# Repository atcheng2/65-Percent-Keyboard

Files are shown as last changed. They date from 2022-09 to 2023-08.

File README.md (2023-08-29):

# 65-Percent-Keyboard



QMK Based Keyboard based on the ATmega32A and the VUSB protocol. This build
implements an ANSI 65% layout for standard MX-style switches. The ATmega32A is
implemented over the more standard ATmega32u4 that has native USB support due to
budget constraints and part availability.

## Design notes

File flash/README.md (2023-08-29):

# Basic Flashing Sequence

## Flashing USBaspLoader

1. Connect ISP pins on board to ISP programmer
2. Use `make check` to ensure a proper connection
3. When proper connection is ensured, use `make fuse` to set fuses
4. After fuses are set, use `make flash` flash USBaspLoader

The relevant hex file is `main.hex`, which was compiled using a modified version
of
[USBaspLoader-Atmega32](https://github.com/khairulhasanmd/USBaspLoader-Atmega32)
that takes into account the settings found in
[`bootloaderconfig.h`](bootloaderconfig.h).

## Flashing QMK

1. Connect device to computer via USB port
2. Short bootloader jumper on device and press the reset switch
3. If done properly, the board should be recognized as a USB device
4. Flash QMK with `make upload`

The relevant hex file is `andyboard_default.hex`, which was compiled using a
modified version of [QMK](https:github.com/atcheng2/qmk_firmware).

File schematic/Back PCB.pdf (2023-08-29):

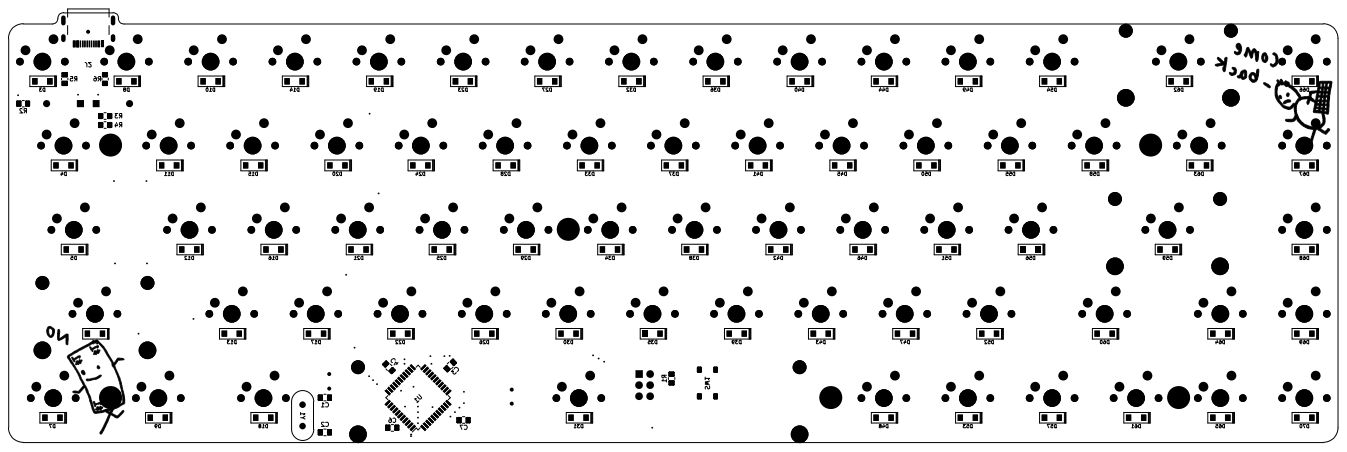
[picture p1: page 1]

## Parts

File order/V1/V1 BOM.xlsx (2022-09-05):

Comment | Designator | Footprint | JLCPCB Part #（optional）
ATMega32A-AU | U1 | TQFP-44_10x10mm_P0.8mm

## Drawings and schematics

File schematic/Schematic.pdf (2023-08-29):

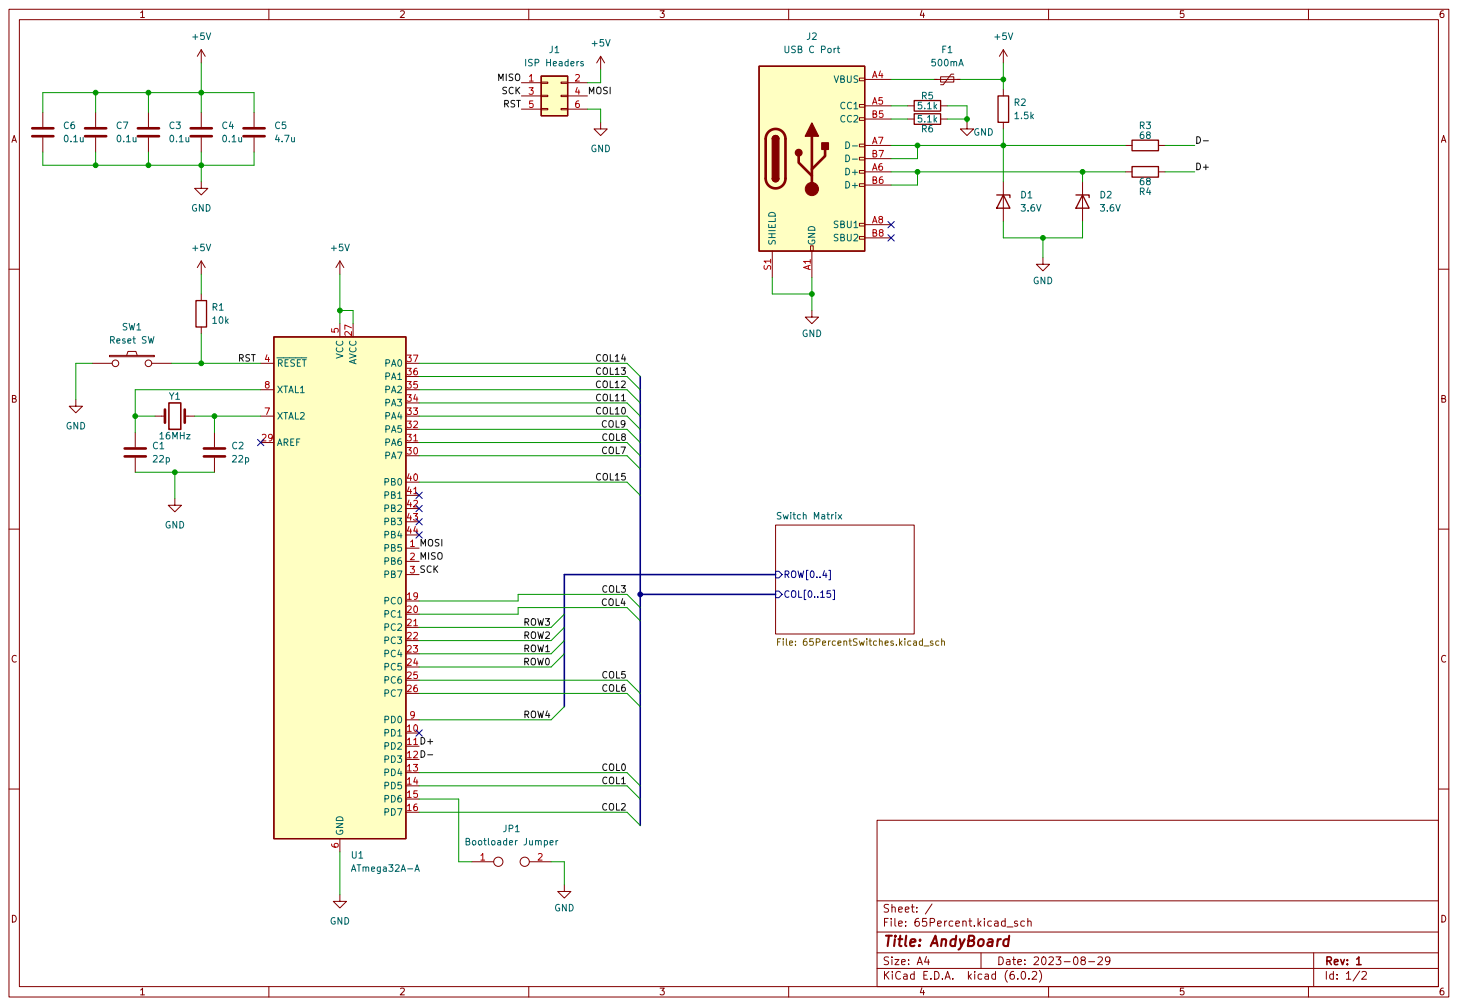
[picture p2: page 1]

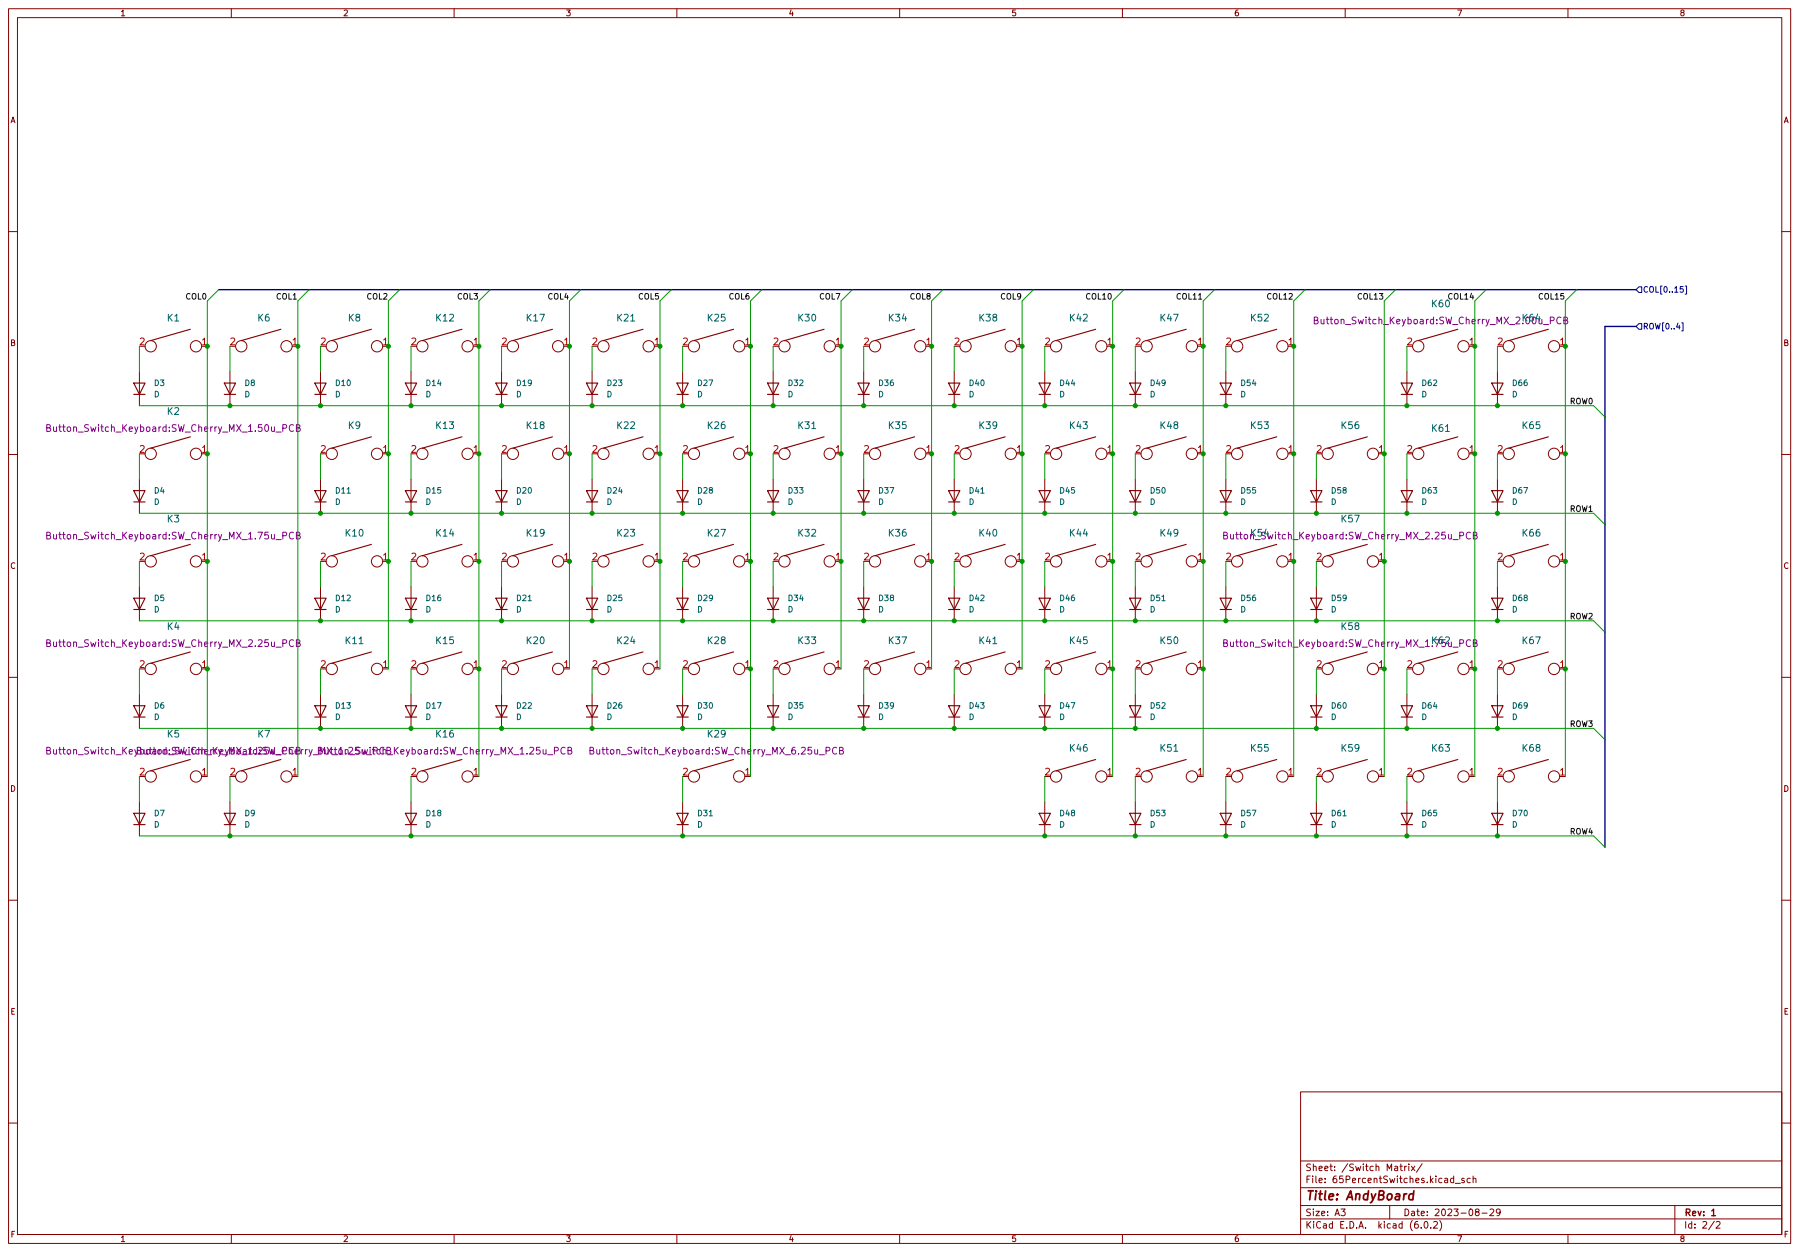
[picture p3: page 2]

File: 65PercentSwitches.kicad_sch Sheet: /Switch Matrix/
Id: 2/2 Title: AndyBoard

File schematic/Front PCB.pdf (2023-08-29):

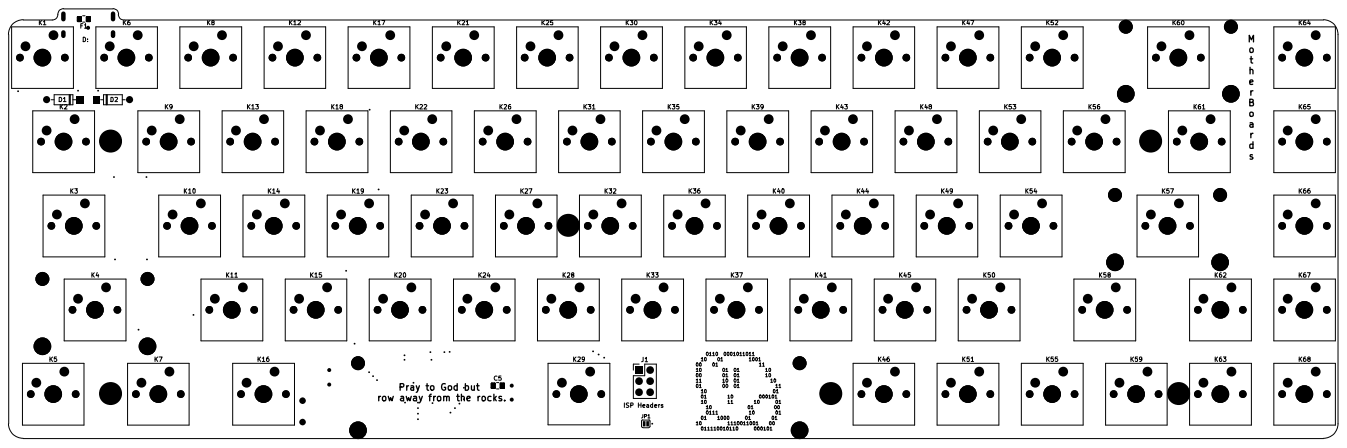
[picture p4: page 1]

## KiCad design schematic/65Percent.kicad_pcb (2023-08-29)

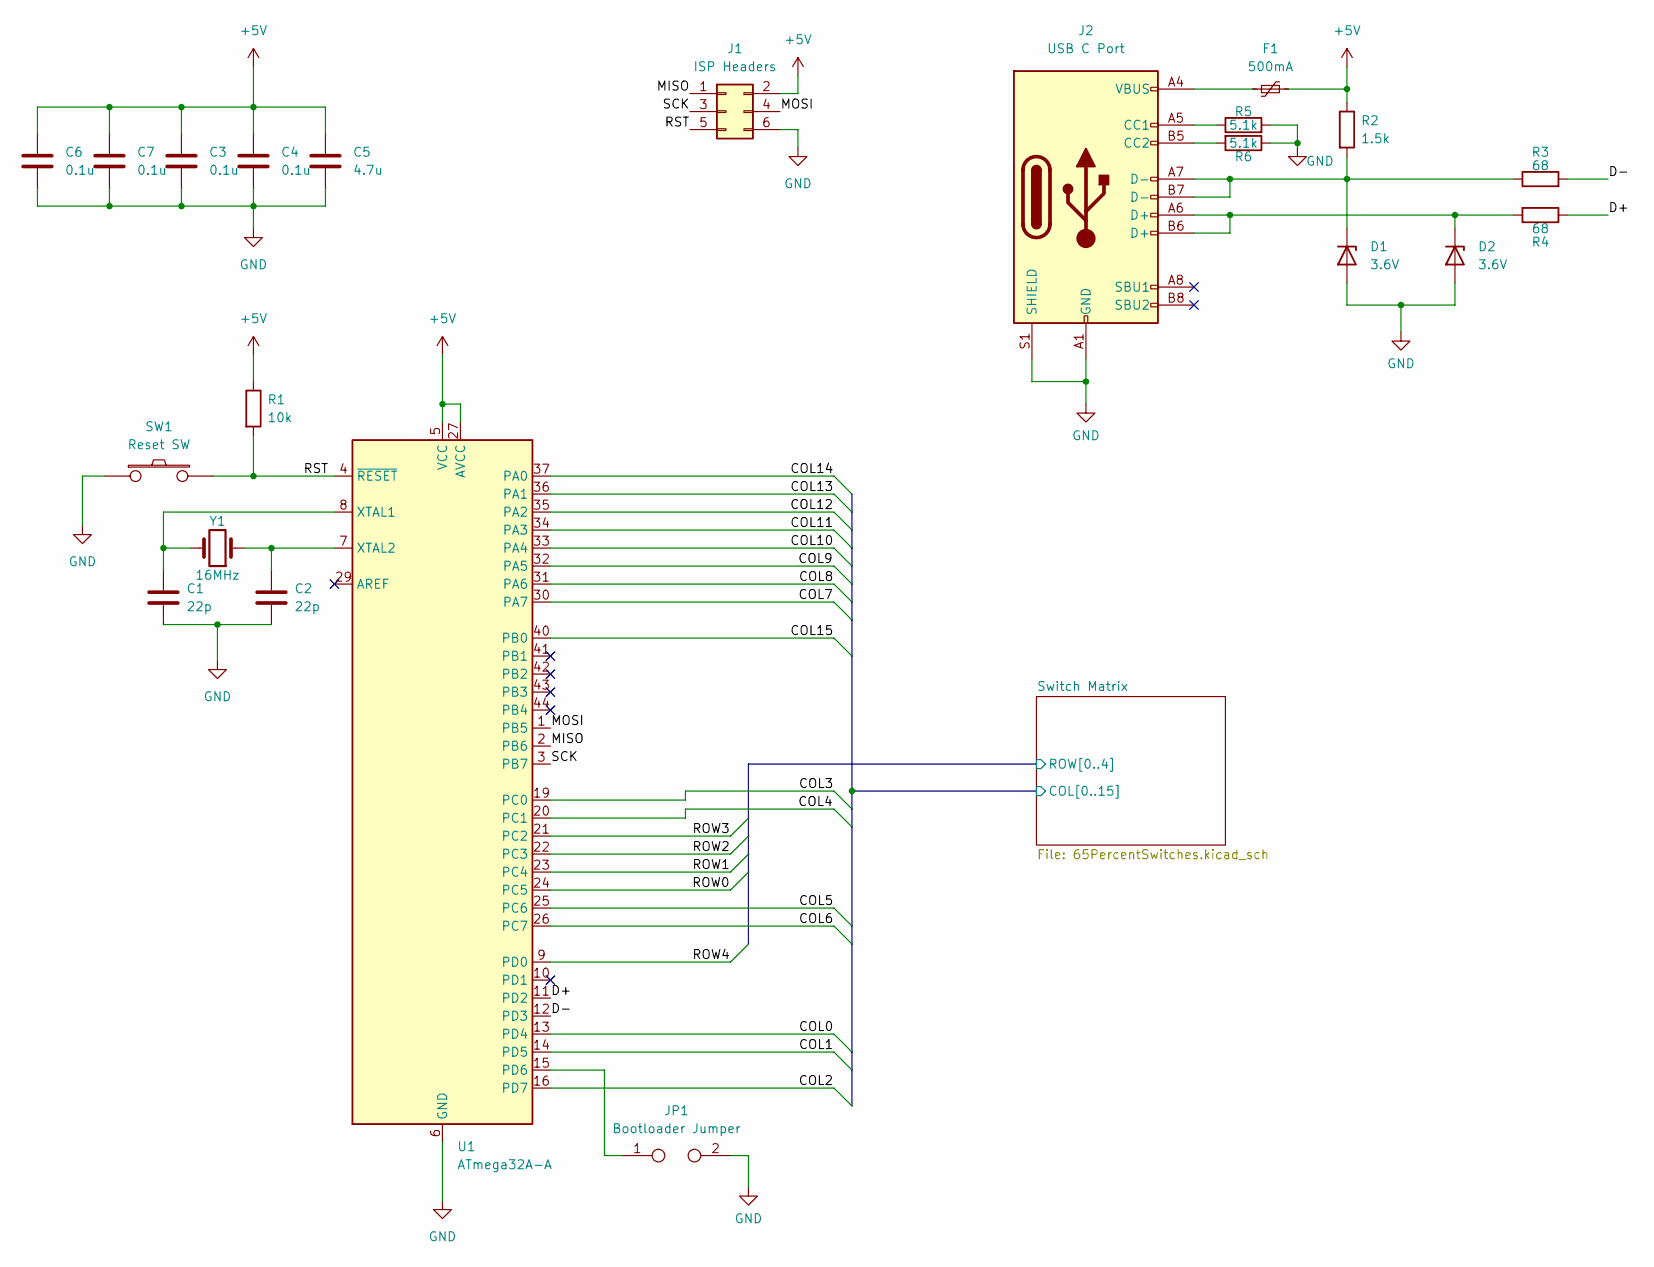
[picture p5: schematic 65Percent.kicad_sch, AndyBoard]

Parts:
C1, C2: 22p; C_0805_2012Metric_Pad1.18x1.45mm_HandSolder
C3, C4, C6, C7: 0.1u; C_0805_2012Metric_Pad1.18x1.45mm_HandSolder
C5: 4.7u; C_0805_2012Metric_Pad1.18x1.45mm_HandSolder
D1, D2: 3.6V; D_DO-35_SOD27_P7.62mm_Horizontal
F1: 500mA; Fuse_0805_2012Metric_Pad1.15x1.40mm_HandSolder
J1: ISP Headers; PinHeader_2x03_P2.54mm_Vertical
J2: USB C Port; USB_C_2169900002
JP1: Bootloader Jumper; SOLDER_JUMPER_2
R1: 10k; R_0805_2012Metric_Pad1.20x1.40mm_HandSolder
R2: 1.5k; R_0805_2012Metric_Pad1.20x1.40mm_HandSolder
R3, R4: 68; R_0805_2012Metric_Pad1.20x1.40mm_HandSolder
R5, R6: 5.1k; R_0805_2012Metric_Pad1.20x1.40mm_HandSolder
SW1: Reset SW; Pushbutton_PTS526
U1: ATmega32A-A; TQFP-44_10x10mm_P0.8mm
Y1: 16MHz; Clock_THT

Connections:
+5V: C3.1, C4.1, C5.1, C6.1, C7.1, F1.2, J1.2, R1.1, R2.1, U1.5 (VCC), U1.17 (VCC), U1.27 (AVCC), U1.38 (VCC)
/D+: R4.1, U1.11 (PD2)
/D-: R3.2, U1.12 (PD3)
/MISO: J1.1, U1.2 (PB6)
/MOSI: J1.4, U1.1 (PB5)
/RST: J1.5, R1.2, SW1.2, U1.4 (~RESET)
/SCK: J1.3, U1.3 (PB7)
/Switch Matrix/COL0: U1.13 (PD4); also elsewhere on the board
/Switch Matrix/COL1: U1.14 (PD5); also elsewhere on the board
/Switch Matrix/COL2: U1.16 (PD7); also elsewhere on the board
/Switch Matrix/COL3: U1.19 (PC0); also elsewhere on the board
/Switch Matrix/COL4: U1.20 (PC1); also elsewhere on the board
/Switch Matrix/COL5: U1.25 (PC6); also elsewhere on the board
/Switch Matrix/COL6: U1.26 (PC7); also elsewhere on the board
/Switch Matrix/COL7: U1.30 (PA7); also elsewhere on the board
/Switch Matrix/COL8: U1.31 (PA6); also elsewhere on the board
/Switch Matrix/COL9: U1.32 (PA5); also elsewhere on the board
/Switch Matrix/COL10: U1.33 (PA4); also elsewhere on the board
/Switch Matrix/COL11: U1.34 (PA3); also elsewhere on the board
/Switch Matrix/COL12: U1.35 (PA2); also elsewhere on the board
/Switch Matrix/COL13: U1.36 (PA1); also elsewhere on the board
/Switch Matrix/COL14: U1.37 (PA0); also elsewhere on the board
/Switch Matrix/COL15: U1.40 (PB0); also elsewhere on the board
/Switch Matrix/ROW0: U1.24 (PC5); also elsewhere on the board
/Switch Matrix/ROW1: U1.23 (PC4); also elsewhere on the board
/Switch Matrix/ROW2: U1.22 (PC3); also elsewhere on the board
/Switch Matrix/ROW3: U1.21 (PC2); also elsewhere on the board
/Switch Matrix/ROW4: U1.9 (PD0); also elsewhere on the board
GND: C1.2, C2.2, C3.2, C4.2, C5.2, C6.2, C7.2, D1.2 (A), D2.2 (A), J1.6, J2.A1 (GND), J2.A12 (GND), J2.B1 (GND), J2.B12 (GND), J2.S1 (SHIELD), JP1.2, R5.2, R6.1, SW1.1, U1.6 (GND), U1.18 (GND), U1.28 (GND), U1.39 (GND)
unnamed: C1.1, U1.8 (XTAL1), Y1.2
unnamed: C2.1, U1.7 (XTAL2), Y1.1
unnamed: D1.1 (K), J2.A7 (D-), J2.B7 (D-), R2.2, R3.1
unnamed: D2.1 (K), J2.A6 (D+), J2.B6 (D+), R4.2
unnamed: F1.1, J2.A4 (VBUS), J2.A9 (VBUS), J2.B4 (VBUS), J2.B9 (VBUS)
unnamed: J2.A5 (CC1), R5.1
unnamed: J2.B5 (CC2), R6.2
unnamed: JP1.1, U1.15 (PD6)

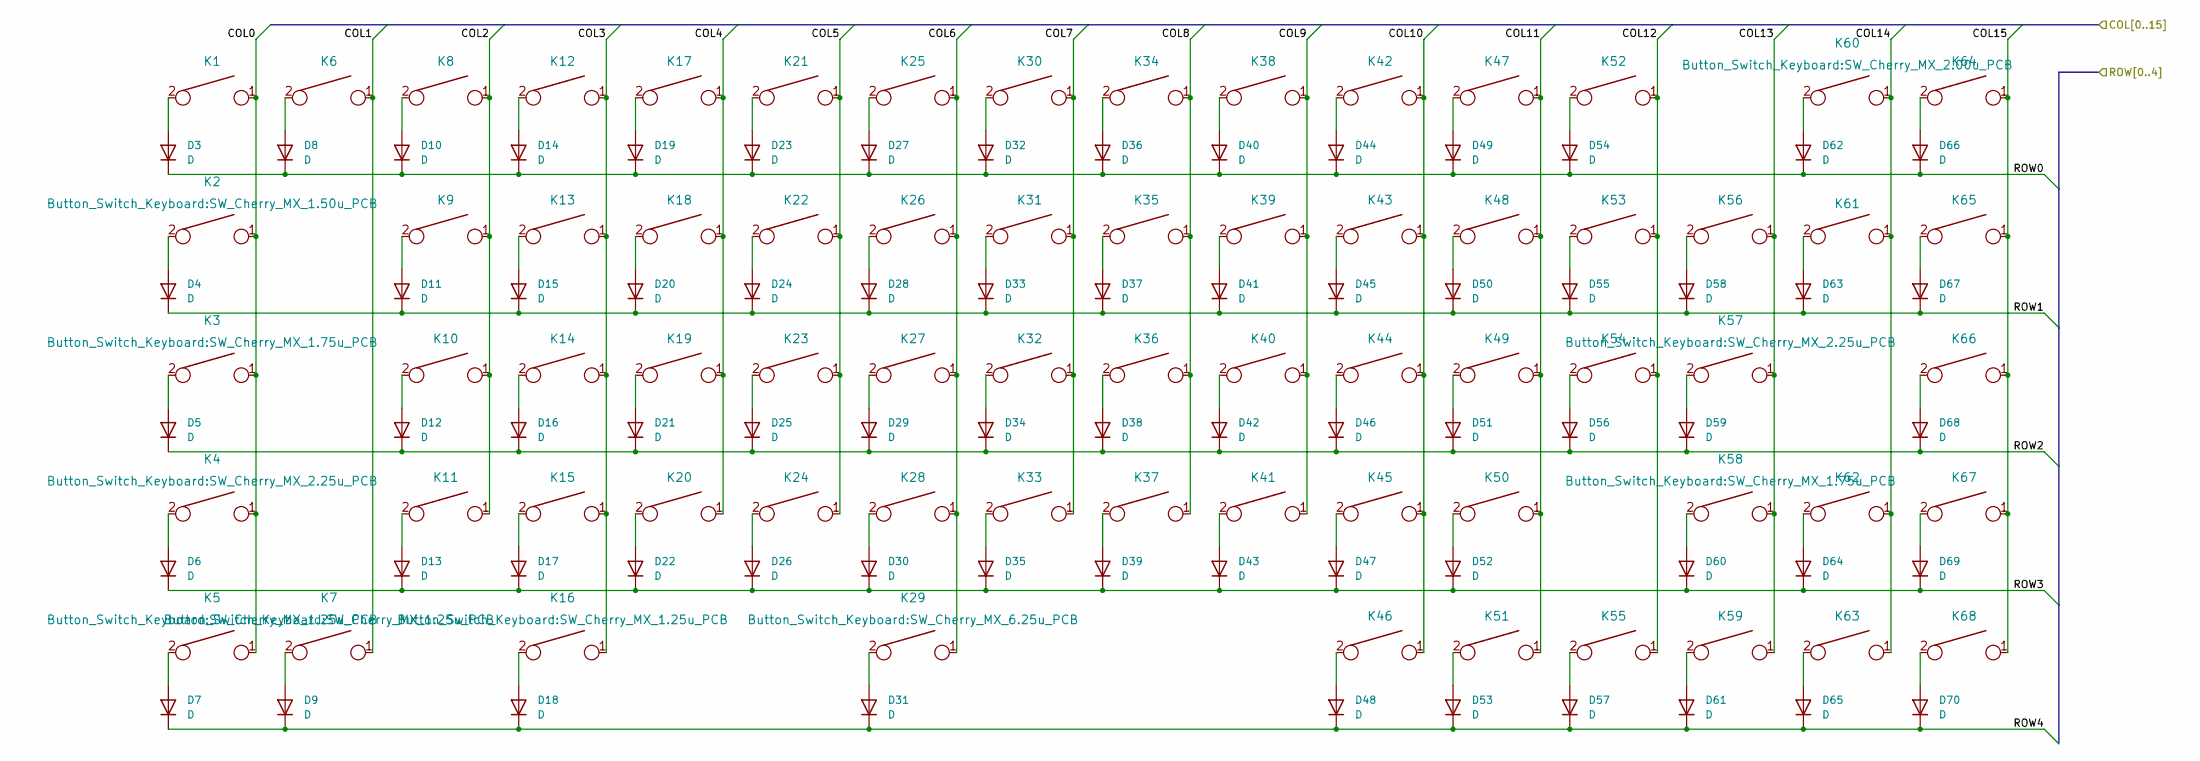
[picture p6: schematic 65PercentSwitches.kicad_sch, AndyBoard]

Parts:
D3, D4, D5, D6, D7, D8, D9, D10, D11, D12, D13, D14, D15, D16, D17, D18, D19, D20, D21, D22, D23, D24, D25, D26, D27, D28, D29, D30, D31, D32, D33, D34, D35, D36, D37, D38, D39, D40, D41, D42, D43, D44, D45, D46, D47, D48, D49, D50, D51, D52, D53, D54, D55, D56, D57, D58, D59, D60, D61, D62, D63, D64, D65, D66, D67, D68, D69, D70: D; D_SOD123W_hand
K1, K6, K8, K9, K10, K11, K12, K13, K14, K15, K17, K18, K19, K20, K21, K22, K23, K24, K25, K26, K27, K28, K30, K31, K32, K33, K34, K35, K36, K37, K38, K39, K40, K41, K42, K43, K44, K45, K46, K47, K48, K49, K50, K51, K52, K53, K54, K55, K56, K59, K62, K63, K64, K65, K66, K67, K68: KEYSW; SW_Cherry_MX_1.00u_PCB
K2, K61: KEYSW; SW_Cherry_MX_1.50u_PCB
K3, K58: KEYSW; SW_Cherry_MX_1.75u_PCB
K4, K57: KEYSW; SW_Cherry_MX_2.25u_PCB
K5, K7, K16: KEYSW; SW_Cherry_MX_1.25u_PCB
K29: KEYSW; SW_Cherry_MX_6.25u_PCB
K60: KEYSW; SW_Cherry_MX_2.00u_PCB

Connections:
/Switch Matrix/COL0: K1.1, K2.1, K3.1, K4.1, K5.1; also elsewhere on the board
/Switch Matrix/COL1: K6.1, K7.1; also elsewhere on the board
/Switch Matrix/COL2: K8.1, K9.1, K10.1, K11.1; also elsewhere on the board
/Switch Matrix/COL3: K12.1, K13.1, K14.1, K15.1, K16.1; also elsewhere on the board
/Switch Matrix/COL4: K17.1, K18.1, K19.1, K20.1; also elsewhere on the board
/Switch Matrix/COL5: K21.1, K22.1, K23.1, K24.1; also elsewhere on the board
/Switch Matrix/COL6: K25.1, K26.1, K27.1, K28.1, K29.1; also elsewhere on the board
/Switch Matrix/COL7: K30.1, K31.1, K32.1, K33.1; also elsewhere on the board
/Switch Matrix/COL8: K34.1, K35.1, K36.1, K37.1; also elsewhere on the board
/Switch Matrix/COL9: K38.1, K39.1, K40.1, K41.1; also elsewhere on the board
/Switch Matrix/COL10: K42.1, K43.1, K44.1, K45.1, K46.1; also elsewhere on the board
/Switch Matrix/COL11: K47.1, K48.1, K49.1, K50.1, K51.1; also elsewhere on the board
/Switch Matrix/COL12: K52.1, K53.1, K54.1, K55.1; also elsewhere on the board
/Switch Matrix/COL13: K56.1, K57.1, K58.1, K59.1; also elsewhere on the board
/Switch Matrix/COL14: K60.1, K61.1, K62.1, K63.1; also elsewhere on the board
/Switch Matrix/COL15: K64.1, K65.1, K66.1, K67.1, K68.1; also elsewhere on the board
/Switch Matrix/ROW0: D3.1 (K), D8.1 (K), D10.1 (K), D14.1 (K), D19.1 (K), D23.1 (K), D27.1 (K), D32.1 (K), D36.1 (K), D40.1 (K), D44.1 (K), D49.1 (K), D54.1 (K), D62.1 (K), D66.1 (K); also elsewhere on the board
/Switch Matrix/ROW1: D4.1 (K), D11.1 (K), D15.1 (K), D20.1 (K), D24.1 (K), D28.1 (K), D33.1 (K), D37.1 (K), D41.1 (K), D45.1 (K), D50.1 (K), D55.1 (K), D58.1 (K), D63.1 (K), D67.1 (K); also elsewhere on the board
/Switch Matrix/ROW2: D5.1 (K), D12.1 (K), D16.1 (K), D21.1 (K), D25.1 (K), D29.1 (K), D34.1 (K), D38.1 (K), D42.1 (K), D46.1 (K), D51.1 (K), D56.1 (K), D59.1 (K), D68.1 (K); also elsewhere on the board
/Switch Matrix/ROW3: D6.1 (K), D13.1 (K), D17.1 (K), D22.1 (K), D26.1 (K), D30.1 (K), D35.1 (K), D39.1 (K), D43.1 (K), D47.1 (K), D52.1 (K), D60.1 (K), D64.1 (K), D69.1 (K); also elsewhere on the board
/Switch Matrix/ROW4: D7.1 (K), D9.1 (K), D18.1 (K), D31.1 (K), D48.1 (K), D53.1 (K), D57.1 (K), D61.1 (K), D65.1 (K), D70.1 (K); also elsewhere on the board
unnamed: D3.2 (A), K1.2
unnamed: D4.2 (A), K2.2
unnamed: D5.2 (A), K3.2
unnamed: D6.2 (A), K4.2
unnamed: D7.2 (A), K5.2
unnamed: D8.2 (A), K6.2
unnamed: D9.2 (A), K7.2
unnamed: D10.2 (A), K8.2
unnamed: D11.2 (A), K9.2
unnamed: D12.2 (A), K10.2
unnamed: D13.2 (A), K11.2
unnamed: D14.2 (A), K12.2
unnamed: D15.2 (A), K13.2
unnamed: D16.2 (A), K14.2
unnamed: D17.2 (A), K15.2
unnamed: D18.2 (A), K16.2
unnamed: D19.2 (A), K17.2
unnamed: D20.2 (A), K18.2
unnamed: D21.2 (A), K19.2
unnamed: D22.2 (A), K20.2
unnamed: D23.2 (A), K21.2
unnamed: D24.2 (A), K22.2
unnamed: D25.2 (A), K23.2
unnamed: D26.2 (A), K24.2
unnamed: D27.2 (A), K25.2
unnamed: D28.2 (A), K26.2
unnamed: D29.2 (A), K27.2
unnamed: D30.2 (A), K28.2
unnamed: D31.2 (A), K29.2
unnamed: D32.2 (A), K30.2
unnamed: D33.2 (A), K31.2
unnamed: D34.2 (A), K32.2
unnamed: D35.2 (A), K33.2
unnamed: D36.2 (A), K34.2
unnamed: D37.2 (A), K35.2
unnamed: D38.2 (A), K36.2
unnamed: D39.2 (A), K37.2
unnamed: D40.2 (A), K38.2
unnamed: D41.2 (A), K39.2
unnamed: D42.2 (A), K40.2
unnamed: D43.2 (A), K41.2
unnamed: D44.2 (A), K42.2
unnamed: D45.2 (A), K43.2
unnamed: D46.2 (A), K44.2
unnamed: D47.2 (A), K45.2
unnamed: D48.2 (A), K46.2
unnamed: D49.2 (A), K47.2
unnamed: D50.2 (A), K48.2
unnamed: D51.2 (A), K49.2
unnamed: D52.2 (A), K50.2
unnamed: D53.2 (A), K51.2
unnamed: D54.2 (A), K52.2
unnamed: D55.2 (A), K53.2
unnamed: D56.2 (A), K54.2
unnamed: D57.2 (A), K55.2
unnamed: D58.2 (A), K56.2
unnamed: D59.2 (A), K57.2
unnamed: D60.2 (A), K58.2
unnamed: D61.2 (A), K59.2
unnamed: D62.2 (A), K60.2
unnamed: D63.2 (A), K61.2
unnamed: D64.2 (A), K62.2
unnamed: D65.2 (A), K63.2
unnamed: D66.2 (A), K64.2
unnamed: D67.2 (A), K65.2
unnamed: D68.2 (A), K66.2
unnamed: D69.2 (A), K67.2
unnamed: D70.2 (A), K68.2

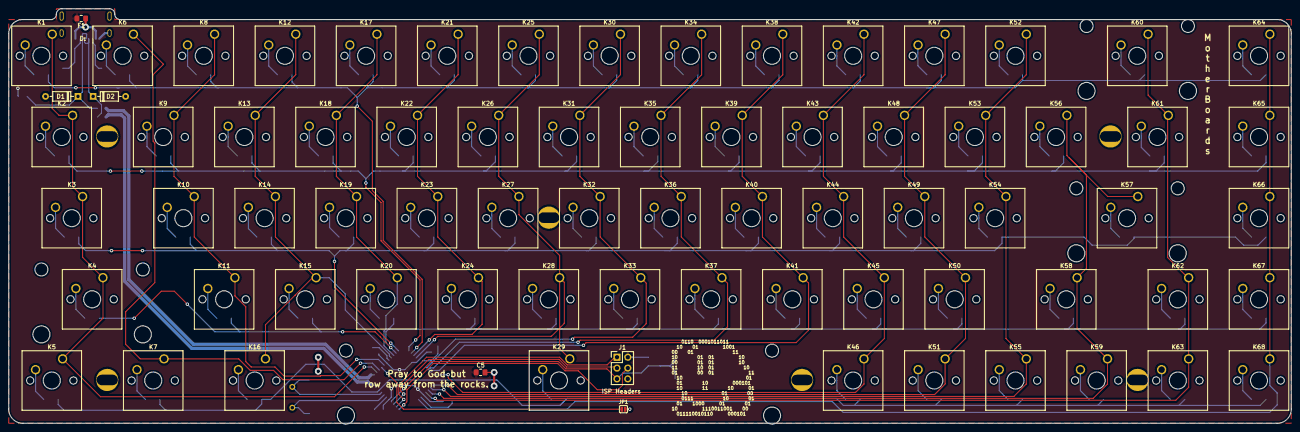
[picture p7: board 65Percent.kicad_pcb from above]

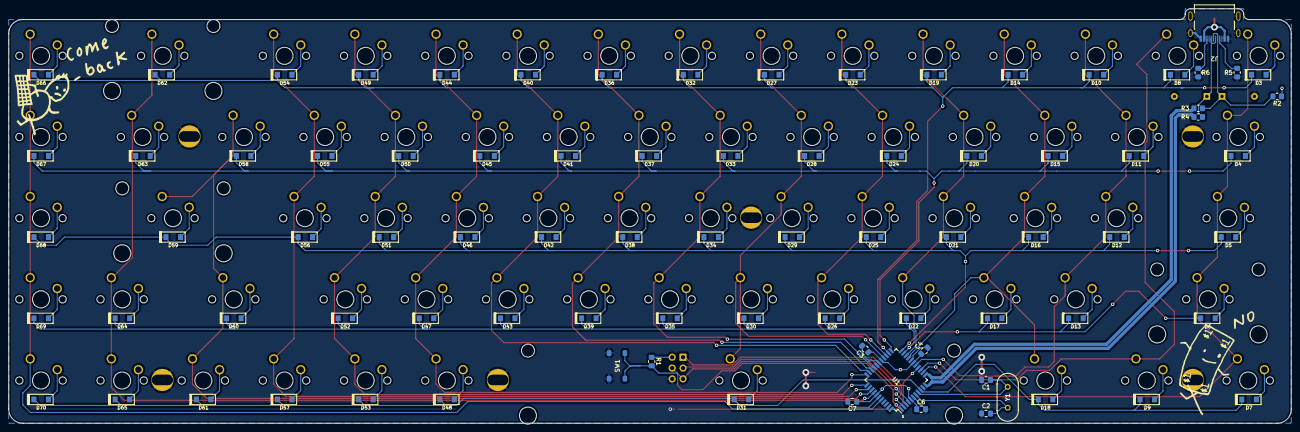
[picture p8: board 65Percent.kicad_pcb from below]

Board: 2 copper layers, 301.0 x 97.3 mm, 158 parts (84 on the bottom side), 105 nets.

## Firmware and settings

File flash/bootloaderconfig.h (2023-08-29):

/* Name: bootloaderconfig.h
 * Project: USBaspLoader
 * Author: Christian Starkjohann
 * Author: Stephan Baerwolf
 * Creation Date: 2007-12-08
 * Modification Date: 2013-03-31
 * Tabsize: 4
 * Copyright: (c) 2007 by OBJECTIVE DEVELOPMENT Software GmbH
 * License: GNU GPL v2 (see License.txt)
 */

#ifndef __bootloaderconfig_h_included__
#define __bootloaderconfig_h_included__
#include "../misc/iofixes.h"

/*
General Description:
This file (together with some settings in Makefile) configures the boot loader
according to the hardware.

This file contains (besides the hardware configuration normally found in
usbconfig.h) two functions or macros: bootLoaderInit() and
bootLoaderCondition(). Whether you implement them as macros or as static
inline functions is up to you, decide based on code size and convenience.

bootLoaderInit() is called as one of the first actions after reset. It should
be a minimum initialization of the hardware so that the boot loader condition
can be read. This will usually consist of activating a pull-up resistor for an
external jumper which selects boot loader mode.

bootLoaderCondition() is called immediately after initialization and in each
main loop iteration. If it returns TRUE, the boot loader will be active. If it
returns FALSE, the boot loader jumps to address 0 (the loaded application)
immediately.

For compatibility with Thomas Fischl's avrusbboot, we also support the macro
names BOOTLOADER_INIT and BOOTLOADER_CONDITION for this functionality. If
these macros are defined, the boot loader usees them.
*/

/* ---------------------------- Macro Magic ---------------------------- */
#define		PIN_CONCAT(a,b)			a ## b
#define		PIN_CONCAT3(a,b,c)		a ## b ## c

#define		PIN_PORT(a)			PIN_CONCAT(PORT, a)
#define		PIN_PIN(a)			PIN_CONCAT(PIN, a)
#define		PIN_DDR(a)			PIN_CONCAT(DDR, a)

#define		PIN(a, b)			PIN_CONCAT3(P, a, b)

/* ---------------------------- Hardware Config ---------------------------- */

#ifndef USB_CFG_IOPORTNAME
  #define USB_CFG_IOPORTNAME      D
#endif
/* This is the port where the USB bus is connected. When you configure it to
 * "B", the registers PORTB, PINB and DDRB will be used.
 */
#ifndef USB_CFG_INTPORT_BIT
  #define USB_CFG_INTPORT_BIT 2
#endif
/* Not all devices have their INT0 on PD2.
 * Since "INT0" and "USB_CFG_DPLUS_BIT" should get the same signals,
 * map them to be ideally the same:
 * So abstract "USB_CFG_DPLUS_BIT" to this one here.
 */

#ifndef USB_CFG_DMINUS_BIT
  /* This is Revision 3 and later (where PD6 and PD7 were swapped */
  // #define USB_CFG_DMINUS_BIT      7    /* Rev.2 and previous was 6 */
  #define USB_CFG_DMINUS_BIT  3
#endif
/* This is the bit number in USB_CFG_IOPORT where the USB D- line is connected.
 * This may be any bit in the port.
 */
#ifndef USB_CFG_DPLUS_BIT
  #define USB_CFG_DPLUS_BIT       USB_CFG_INTPORT_BIT
#endif
/* This is the bit number in USB_CFG_IOPORT where the USB D+ line is connected.
 * This may be any bit in the port. Please note that D+ must also be connected
 * to interrupt pin INT0!
 */
#ifndef JUMPER_PORT
  #define JUMPER_PORT		USB_CFG_IOPORTNAME
#endif
/* 
 * jumper is connected to this port
 */
#ifndef JUMPER_BIT
  /* This is Revision 3 and later (where PD6 and PD7 were swapped */
  // #define JUMPER_BIT           7       /* Rev.2 and previous was 7 */
  #define JUMPER_BIT           6
#endif
/* 
 * jumper is connected to this bit in port "JUMPER_PORT", active low
 */
#define USB_CFG_CLOCK_KHZ       (F_CPU/1000)
/* Clock rate of the AVR in MHz. Legal values are 12000, 16000 or 16500.
 * The 16.5 MHz version of the code requires no crystal, it tolerates +/- 1%
 * deviation from the nominal frequency. All other rates require a precision
 * of 2000 ppm and thus a crystal!
 * Default if not specified: 12 MHz
 */

/* ----------------------- Optional Hardware Config ------------------------ */

/* #define USB_CFG_PULLUP_IOPORTNAME   D */
/* If you connect the 1.5k pullup resistor from D- to a port pin instead of
 * V+, you can connect and disconnect the device from firmware by calling
 * the macros usbDeviceConnect() and usbDeviceDisconnect() (see usbdrv.h).
 * This constant defines the port on which the pullup resistor is connected.
 */
/* #define USB_CFG_PULLUP_BIT          4 */
/* This constant defines the bit number in USB_CFG_PULLUP_IOPORT (defined
 * above) where the 1.5k pullup resistor is connected. See description
 * above for details.
 */

/* ------------------------------------------------------------------------- */
/* ---------------------- feature / code size options ---------------------- */
/* ------------------------------------------------------------------------- */

#ifndef CONFIG_NO__HAVE_READ_LOCK_FUSE
  #define HAVE_READ_LOCK_FUSE	    1
#else
  #define HAVE_READ_LOCK_FUSE	    0
#endif
/*
 * enable the loaders capability to load its lfuse, hfuse and lockbits
 * ...However, programming of these is prohibited...
 */
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

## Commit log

2022-05-31 Initial commit, unrouted v1 of 65 Percent Keyboard
    [65Percent.kicad_pcb, 65Percent.kicad_sch, 65PercentSwitches.kicad_sch]
2022-05-31 Added fuses, column and diode wirings
    [65Percent.kicad_pcb, 65Percent.kicad_sch]
2022-05-31 Completed first pass at v1 board
    [65Percent.kicad_pcb, 65Percent.kicad_sch]
2022-09-05 Final V1 Board, Ordered
    [65Percent-B_Cu.gbr, 65Percent-B_Mask.gbr, 65Percent-B_Paste.gbr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]
2023-08-29 Large file reorganization
    [65Percent-B_Cu.gbr, 65Percent-B_Mask.gbr, 65Percent-B_Paste.gbr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]
2023-08-29 Add pdfs of schematic and pcb
    [65Percent.kicad_pcb, 65Percent.kicad_sch, 65PercentSwitches.kicad_sch]
